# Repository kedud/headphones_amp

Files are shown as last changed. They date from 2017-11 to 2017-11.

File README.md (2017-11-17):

# Headphone amp

This module is an headphone amp (with a gain of 20dB) associated with a blend setting that allow user to listen to both Cue & Mix outputs, the blend potentiometer sets the proportion of each signal sent to the headphones output.

The BoM for this schematics can be found [here](https://octopart.com/bom-tool/wFRvv2qY)

A Mouser cart is also available [here](https://www.mouser.com/ProjectManager/ProjectDetail.aspx?AccessID=5afd9f8ce4)

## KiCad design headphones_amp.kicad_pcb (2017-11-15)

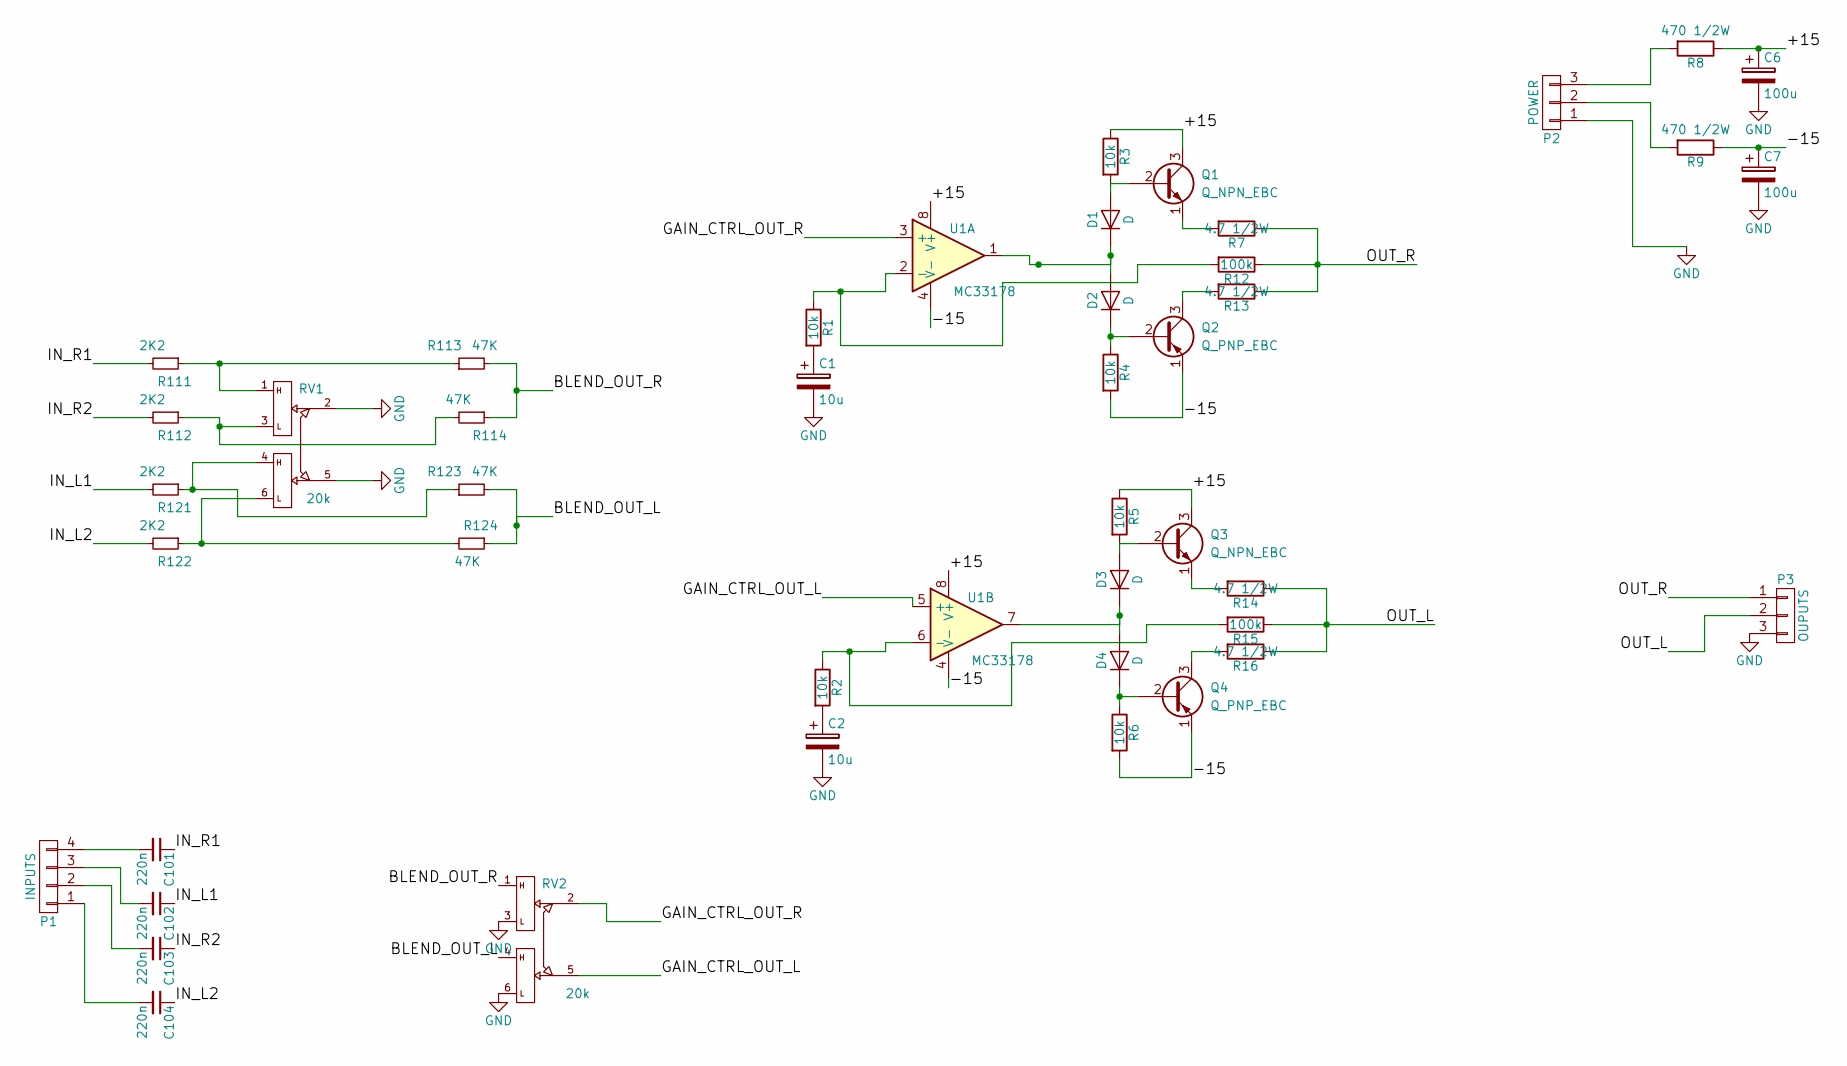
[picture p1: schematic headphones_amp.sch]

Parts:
C1, C2: 10u; CP_5x11mm; Mfg_Part_No USR1V100MDD1TE
C6, C7: 100u; CP_6.3x11mm; Mfg_Part_No ULD1E101MED1TD
C101, C102, C103, C104: 220n; C_Rect_L7.0mm_W3.5mm_P5.00mm; Mfg_Part_No R82EC3220Z370J
D1, D2, D3, D4: D; D_DO-35_SOD27_P7.62mm_Horizontal; Mfg_Part_No 1N4148
P1: INPUTS; Pin_Header_Angled_1x04_Pitch2.54mm; Mfg_Part_No 0
P2: POWER; Pin_Header_Angled_1x03_Pitch2.54mm
P3: OUPUTS; Pin_Header_Angled_1x03_Pitch2.54mm; Mfg_Part_No 0
Q1, Q3: Q_NPN_EBC; TO-18-3; Mfg_Part_No 2N2222
Q2, Q4: Q_PNP_EBC; TO-18-3; Mfg_Part_No 2N2907A
R1, R2, R3, R4, R5, R6: 10k; R_Axial_DIN0204_L3.6mm_D1.6mm_P5.08mm_Horizontal
R7, R13, R14, R16: 4.7 1/2W; R_Axial_DIN0204_L3.6mm_D1.6mm_P5.08mm_Horizontal
R8, R9: 470 1/2W; Resistor_Horizontal_RM7mm
R12, R15: 100k; R_Axial_DIN0204_L3.6mm_D1.6mm_P5.08mm_Horizontal
R111, R112, R121, R122: 2K2; R_Axial_DIN0204_L3.6mm_D1.6mm_P5.08mm_Horizontal
R113, R114, R123, R124: 47K; R_Axial_DIN0204_L3.6mm_D1.6mm_P5.08mm_Horizontal
RV1: 20k; Potentiometer_ALPS_RK097; Mfg_Part_No RK0971210Z2M
RV2: 20k; Potentiometer_ALPS_RK097; Mfg_Part_No RK09712200HA
U1: MC33178; DIP-8_W7.62mm_LongPads

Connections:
/+15: C6.1, Q1.3 (C), Q3.3 (C), R3.1, R5.1, R8.1, U1.8 (V+)
/-15: C7.1, Q2.1 (E), Q4.1 (E), R4.2, R6.2, R9.1, U1.4 (V-)
/BLEND_OUT_L: R123.2, R124.1, RV2.4
/BLEND_OUT_R: R113.2, R114.1, RV2.1
/GAIN_CTRL_OUT_L: RV2.5, U1.5 (+)
/GAIN_CTRL_OUT_R: RV2.2, U1.3 (+)
/IN_L1: C102.1, R121.2
/IN_L2: C104.1, R122.2
/IN_R1: C101.1, R111.2
/IN_R2: C103.1, R112.2
/OUT_L: P3.2, R14.1, R15.1, R16.1
/OUT_R: P3.1, R7.1, R12.1, R13.1
GND: C1.2, C2.2, C6.2, C7.2, P2.1, P3.3, RV1.2, RV1.5, RV2.3, RV2.6
unnamed: C1.1, R1.2
unnamed: C2.1, R2.2
unnamed: C101.2, P1.4
unnamed: C102.2, P1.3
unnamed: C103.2, P1.2
unnamed: C104.2, P1.1
unnamed: D1.1 (K), D2.2 (A), U1.1
unnamed: D1.2 (A), Q1.2 (B), R3.2
unnamed: D2.1 (K), Q2.2 (B), R4.1
unnamed: D3.1 (K), D4.2 (A), U1.7
unnamed: D3.2 (A), Q3.2 (B), R5.2
unnamed: D4.1 (K), Q4.2 (B), R6.1
unnamed: P2.2, R9.2
unnamed: P2.3, R8.2
unnamed: Q1.1 (E), R7.2
unnamed: Q2.3 (C), R13.2
unnamed: Q3.1 (E), R14.2
unnamed: Q4.3 (C), R16.2
unnamed: R1.1, R12.2, U1.2 (-)
unnamed: R2.1, R15.2, U1.6 (-)
unnamed: R111.1, R113.1, RV1.1
unnamed: R112.1, R114.2, RV1.3
unnamed: R121.1, R123.1, RV1.4
unnamed: R122.1, R124.2, RV1.6

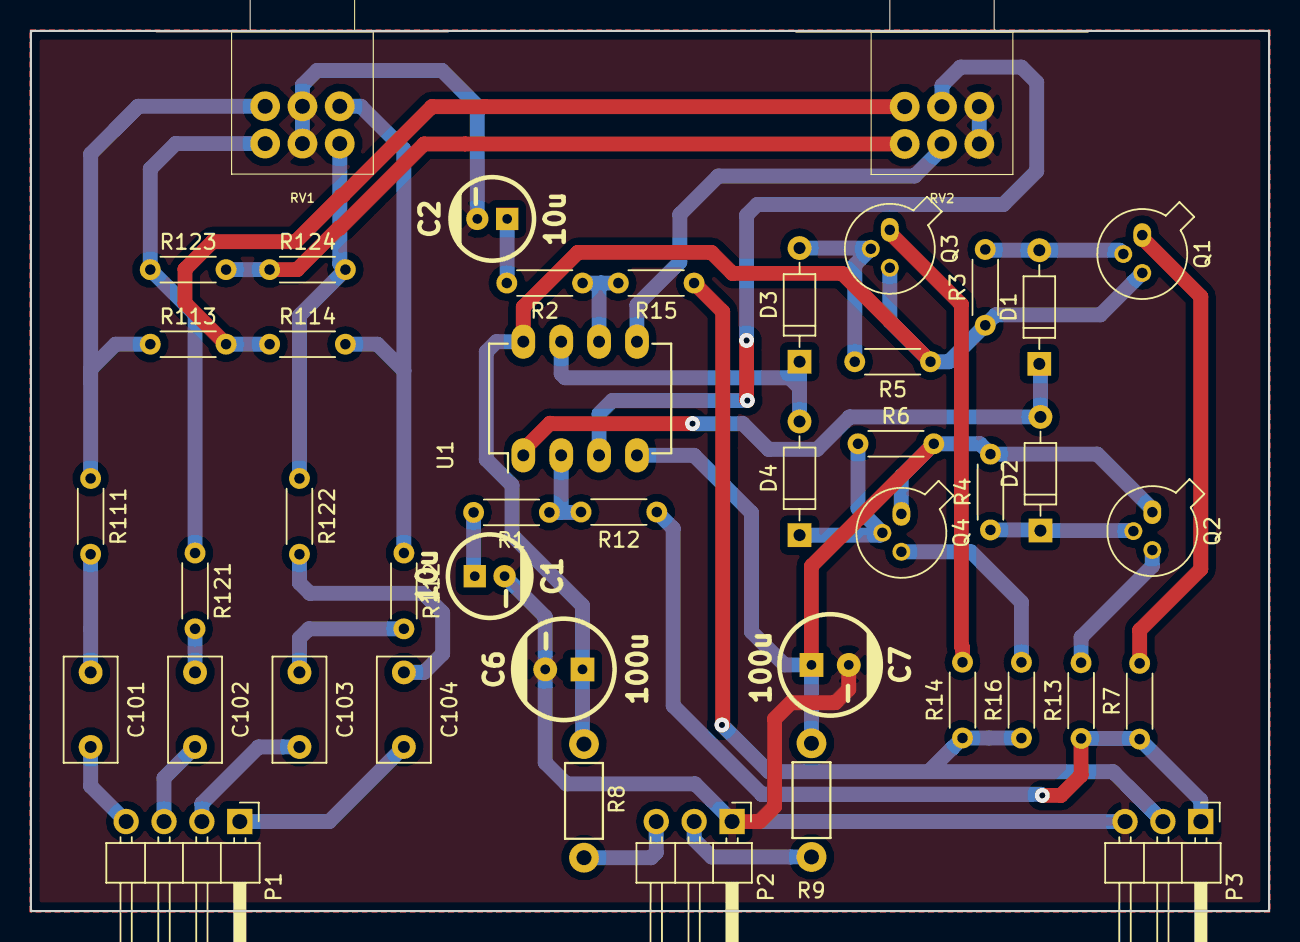
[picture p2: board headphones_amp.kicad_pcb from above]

Board: 2 copper layers, 83.0 x 59.0 mm, 44 parts (0 on the bottom side), 37 nets.

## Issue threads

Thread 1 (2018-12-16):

[Fix] Had input stage before blend input

kedud, 2018-12-16:
Blend input doesn't have an input stage, it causes distortion and gain issues on master output.
An input stage should be added in order to avoid signal crossing issues.

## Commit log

2017-11-17 Updated components references
    [headphones_amp.sch]
2017-11-17 Add missing references
    [headphones_amp.sch]
2017-11-17 Fix BoM links
